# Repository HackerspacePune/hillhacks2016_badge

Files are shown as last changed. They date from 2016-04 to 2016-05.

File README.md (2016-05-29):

PCB badge for hillhacks.in
==========================

Designed in kicad 4.0.2

Based on Adafruit trinket and Digispark designs. Can use either Adafruit's 
trinket/gemma bootloader, or micronucleus(which digispark uses).
Reverse protection for USB and battery with schottky diodes(and supply 
selection also), no voltage regulator, Zener diodes are to clip D+/D- 
voltage level to within USB spec. 1.5k on D- is part of USB spec's Low 
speed USB detection.

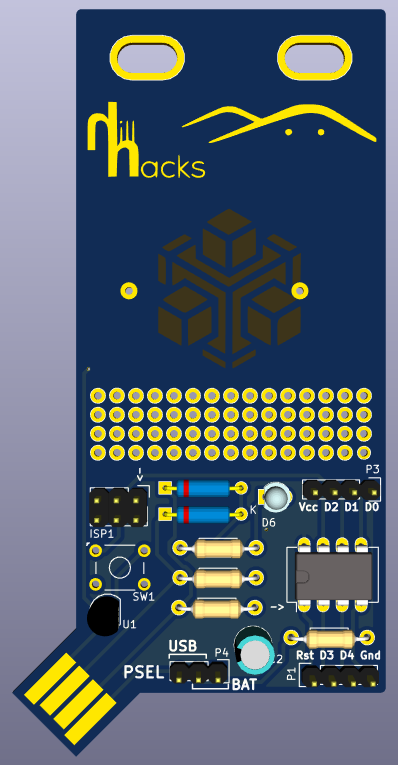
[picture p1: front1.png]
Hillhacks badge


Hillhacks logo is from header on site.

Design uses a footprint(pcb_USB-A) from Inversepath's Usbarmory kicad design https://github.com/inversepath/usbarmory/

Firmware
========

Bootloader: Please follow [these instructions](https://learn.adafruit.com/introducing-trinket/repairing-bootloader) for
installing Adafruit Trinket bootloader onto your badge. This allows you to upload 'sletches' to the badge without an external programmer.

Arduino IDE: Set up arduino IDE to work with your badge from [here](https://learn.adafruit.com/introducing-trinket/setting-up-with-arduino-ide).

Hardware
========

Please see [Schematic.pdf](Schematic.pdf) for schematic. Pin PB0(D0 for arduino) is
connected to push button. PB1(D1) is connected to LED.

NOTE: The button footprint is rotated by 90 degrees by mistake, so you need to bend the button
leads so they can be fit the PCB roated. 

NOTE2: the battery holder pins need to be bent out a bit
to fit the PCB.

Example code
============

Please see [/examples/HillhacksBadge.ino](/examples/HillhacksBadge.ino) for Mitch's example sketch.

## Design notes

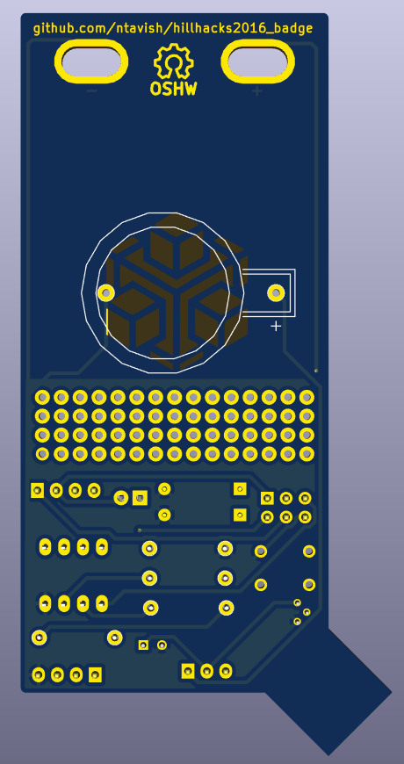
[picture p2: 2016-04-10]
back1.png

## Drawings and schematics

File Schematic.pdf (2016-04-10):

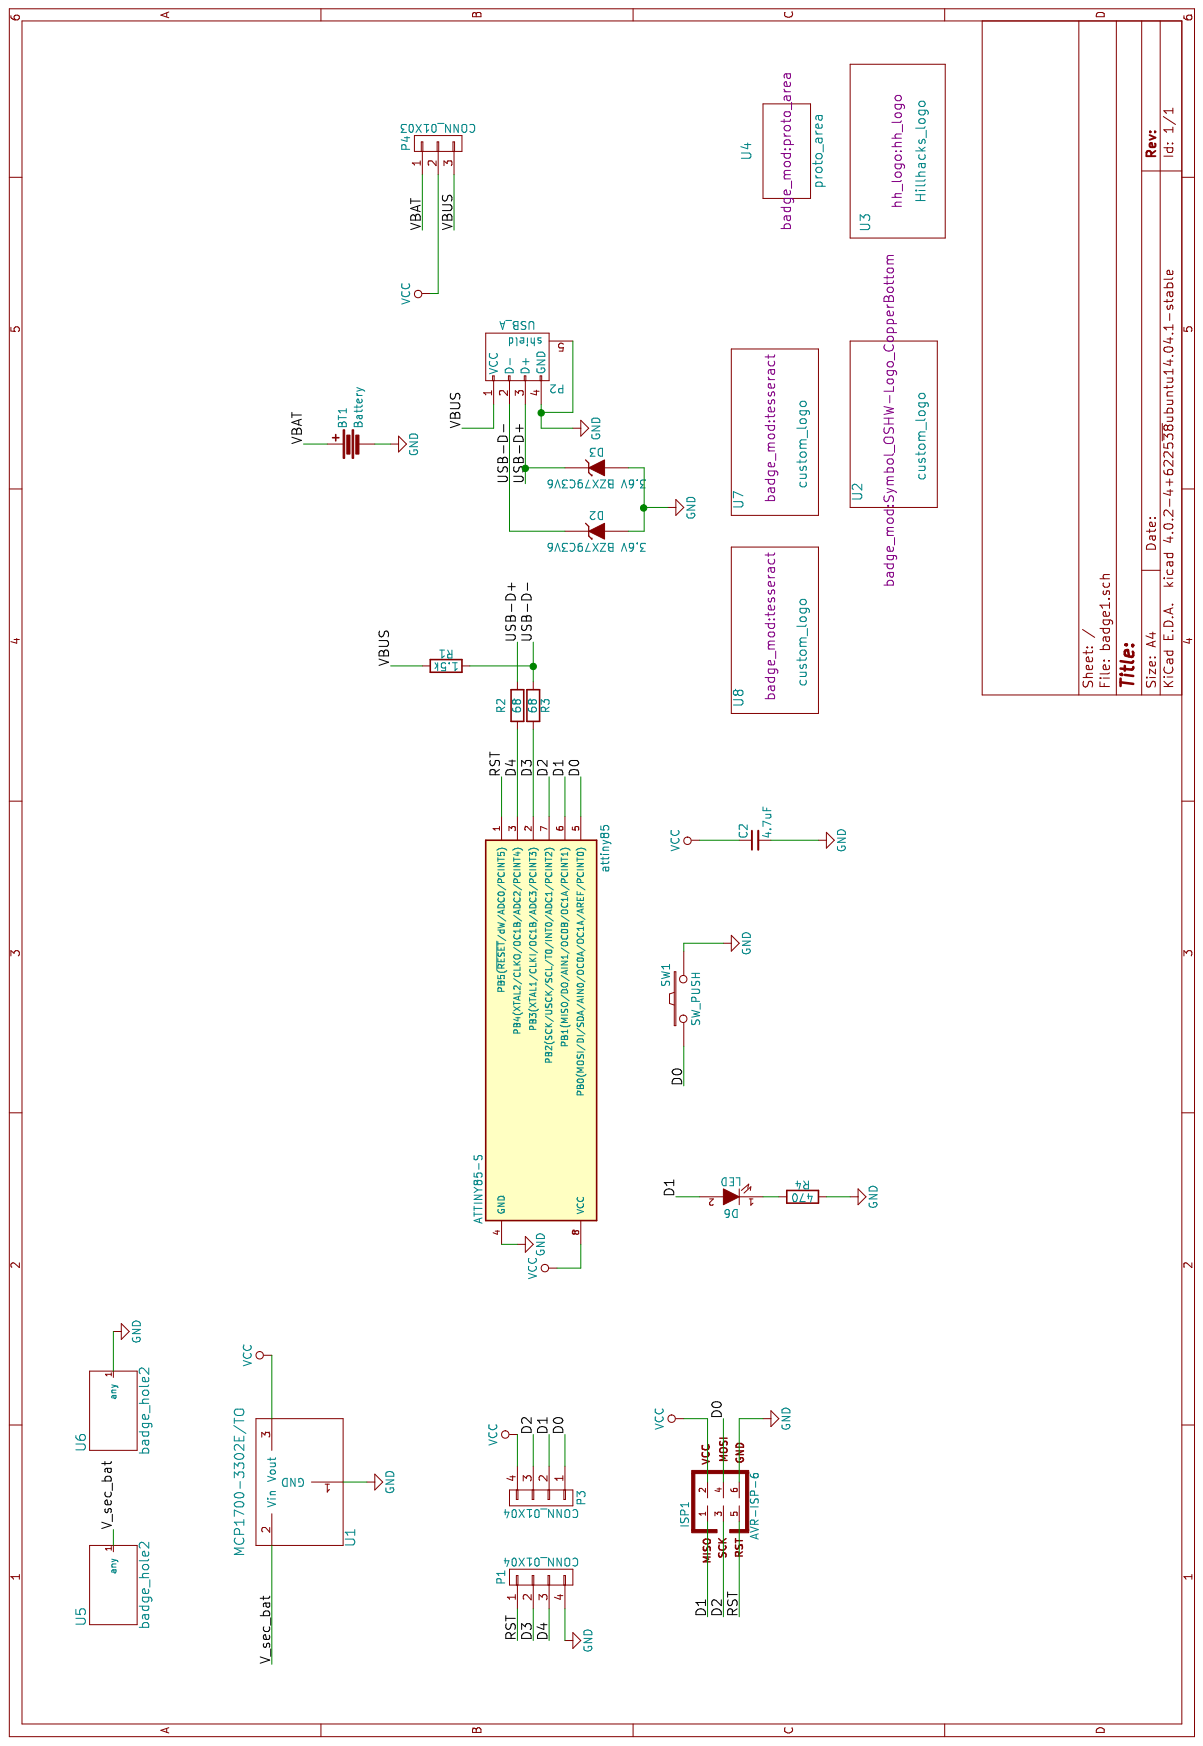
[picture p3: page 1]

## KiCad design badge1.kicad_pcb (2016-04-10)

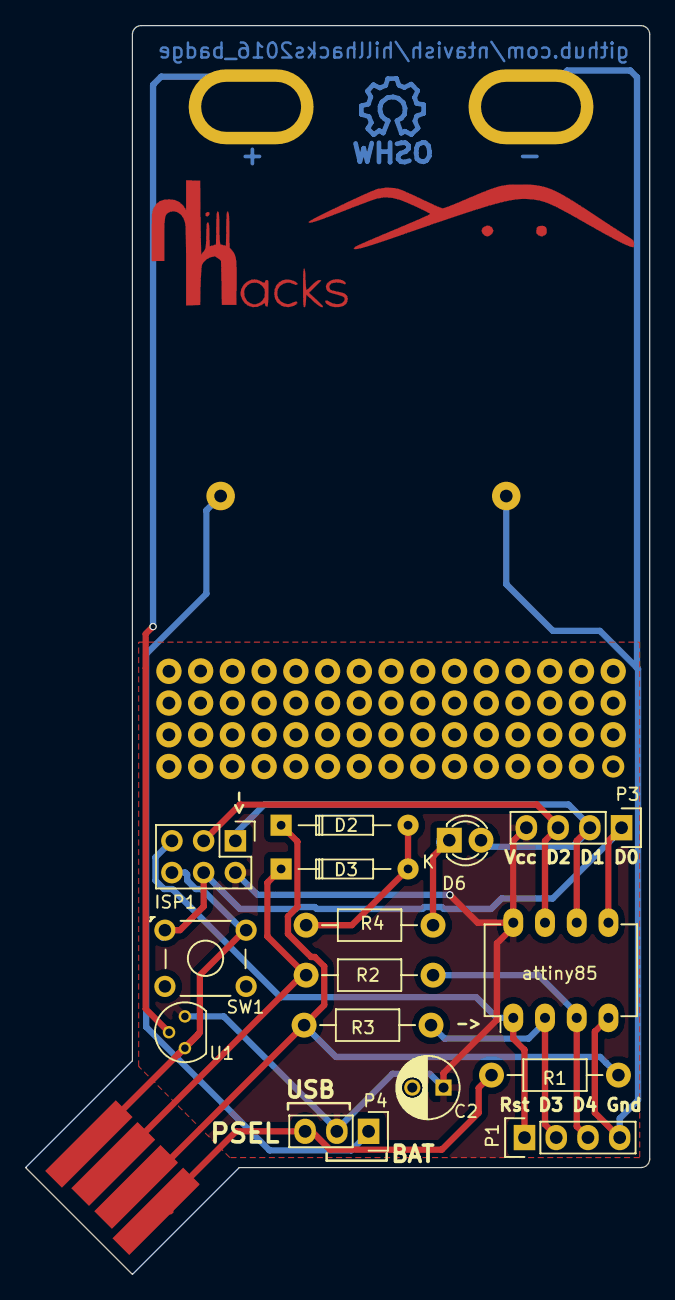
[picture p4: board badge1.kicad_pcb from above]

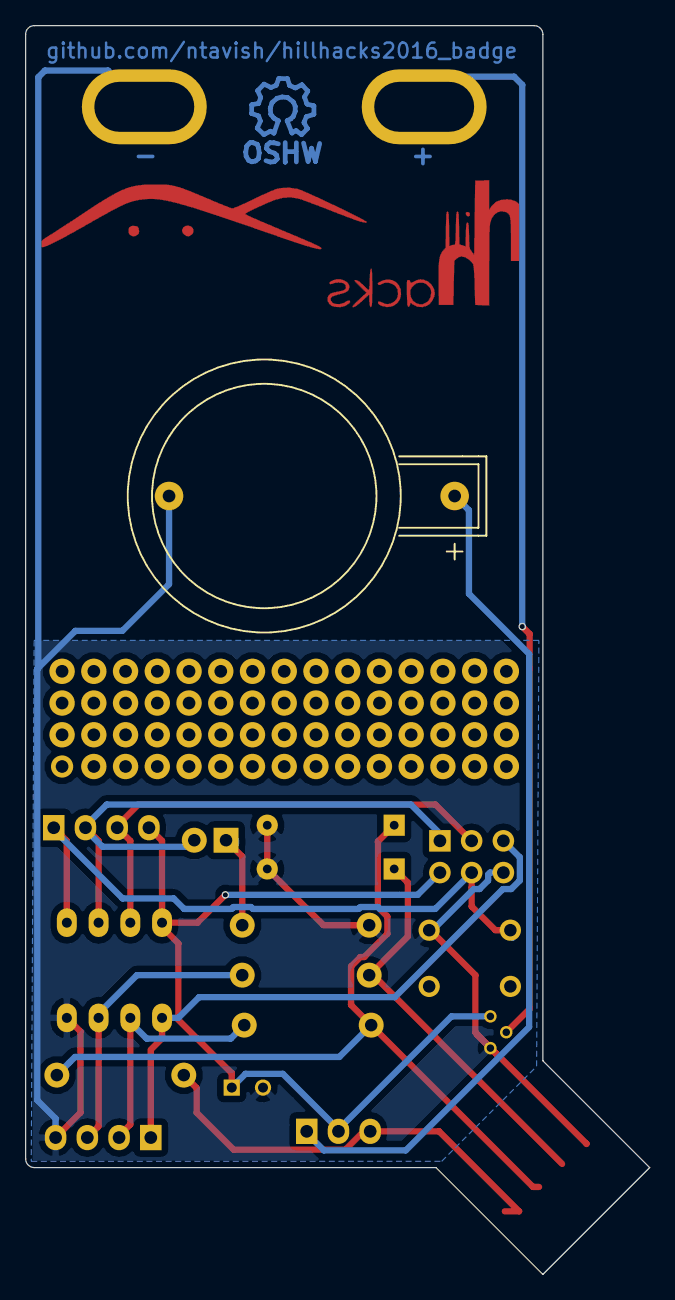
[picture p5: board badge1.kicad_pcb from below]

Board: 2 copper layers, 50.0 x 100.0 mm, 24 parts (2 on the bottom side), 14 nets.

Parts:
BT1: Battery; CR2032H
C2: 4.7uF; C_Radial_D5_L11_P2.5
D2, D3: 3.6V BZX79C3V6; Diode_DO-35_SOD27_Horizontal_RM10
D6: LED; LED-3MM
ISP1: AVR-ISP-6; Pin_Header_Straight_2x03
P1, P3: CONN_01X04; Pin_Header_Straight_1x04
P2: USB_A; usb-PCB
P4: CONN_01X03; Pin_Header_Straight_1x03
R1: 1.5k; Resistor_Horizontal_RM10mm
R2, R3: 68; Resistor_Horizontal_RM10mm
R4: 470; Resistor_Horizontal_RM10mm
SW1: SW_PUSH; OPL_DIP_BUTTON_TS-1109_BEST_SHENZEN
U1: MCP1700-3302E/TO; TO-92_Molded_Narrow
U2: custom_logo; Symbol_OSHW-Logo_CopperBottom
U3: Hillhacks_logo; hh_logo
U4: proto_area
U5, U6: badge_hole2; badge_hole_6mmx3mm(+2mmCu)
U7, U8: custom_logo; tesseract
attiny85: ATTINY85-S; DIP-8_W7.62mm_LongPads

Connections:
/D0: ISP1.4, P3.1, SW1.1, attiny85.5
/D1: D6.2, ISP1.1, P3.2, attiny85.6
/D2: ISP1.3, P3.3, attiny85.7
/D3: P1.2, R3.2, attiny85.2
/D4: P1.3, R2.2, attiny85.3
/RST: ISP1.5, P1.1, attiny85.1
/USB-D+: D3.1, P2.3, R2.1
/USB-D-: D2.1, P2.2, R1.1, R3.1
/VBAT: BT1.1, P4.1
/VBUS: P2.1, P4.3, R1.2
/V_sec_bat: U1.2, U5.1
GND: BT1.2, C2.2, D2.2, D3.2, ISP1.6, P1.4, P2.4, R4.2, SW1.2, U1.1, U6.1, attiny85.4
unnamed: D6.1, R4.1
VCC: C2.1, ISP1.2, P3.4, P4.2, U1.3, attiny85.8

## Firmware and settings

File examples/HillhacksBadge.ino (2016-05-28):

/*
  Hillhacks Badge example sketch

 When first powered up, LED on D1 blinks on and off at 100ms intervals.
 After push button on D0:  LED fades in and out.
 After push button again:  LED blinks kind of randomly
 After push button again:  LED fades in and out quickly
 Push button again: back to beginning to blink LED on and off at 100ms intervals.
 etc.

 The circuit:
 * LED attached from pin 1 to ground
 * pushbutton attached to pin 0 to ground


Hacked from Arduino example sketches:  Blink and Fade
 This example code is in the public domain.
*/

// constants won't change values
const int buttonPin = 0;         // the number of the pushbutton pin
const int ledPin =  1;           // the number of the LED pin
const int MAX_BUTTON_COUNT = 4;  // max number of cool things that can happen by pushing the button
const int MAX_RAND_BLINK = 10;   // number of different blink rates for the random blink for the 3rd button press

// variables will change values
int buttonCount = 0;         // keep track of the number of times the button is pushed

int brightness = 0;          // how bright the LED is when we're in case 1)
int fadeAmount = 5;          // how many points to fade the LED by when we're in case 1)

int randomBlinkState = 0;    // keeps track of where we're at in the random blinking for case 2


// see if the button is being pushed, and if so, increment the buttonCount
int readButton() {  
  int buttonState = 0;   // variable for reading the pushbutton status

  // read the state of the pushbutton value:
  buttonState = digitalRead(buttonPin);  // buttonState will be LOW if button is being pushed

  // if button is being pushed, increment the buttonCount
  if (buttonState == LOW) {
    buttonCount++;
    // reset the buttonCount to 0 if we've reached the max number
    if (buttonCount == MAX_BUTTON_COUNT) {
      buttonCount = 0;
    }
  }  

  // wait for button to stop being pressed
  while (buttonState == LOW) {
    buttonState = digitalRead(buttonPin);  // buttonState will be LOW if button is still being pushed
    delay(10);
  }
}


void setup() {
  // initialize the LED pin as an output:
  pinMode(ledPin, OUTPUT);
  // initialize the pushbutton pin as an input:
  pinMode(buttonPin, INPUT);
  digitalWrite(buttonPin, HIGH);
}

void loop() {
  // See if the button is being pushed -- buttonCount is automatically incremented if it is
  readButton();

  // The LED will do something different depending on the number of times the button has been pushed
  switch(buttonCount) {

    // For case 0, the LED blinks on and off at 10msec intervals
    case 0 :
      digitalWrite(ledPin, HIGH); 
      delay(100);
      digitalWrite(ledPin, LOW);
      delay(100);

      break;  // end of case 0


    // For case 1, the LED fades in and out
    case 1 :
      // set the brightness of the LED on pin 1:
      analogWrite(ledPin, brightness);

      // change the brightness for next time through the loop:
      brightness = brightness + fadeAmount;

      // reverse the direction of the fading at the ends of the fade:
      if (brightness == 0 || brightness == 255) {
        fadeAmount = -fadeAmount ;
      }

      // wait for 30 milliseconds to see the dimming effect
      delay(30);

      break;  // end of case 1


    // For case 2, the LED blinks on and off kind of randomly
    case 2 :

      switch (randomBlinkState) {
        case 0:
          digitalWrite(ledPin, HIGH); 
          delay(100);
          digitalWrite(ledPin, LOW);
          delay(100);
          // increment to next random blink state, and reset to 0 if reached the max state
          randomBlinkState++;
          if (randomBlinkState == MAX_RAND_BLINK) randomBlinkState = 0;
          break;
        case 1:
          digitalWrite(ledPin, HIGH); 
          delay(100);
          digitalWrite(ledPin, LOW);
          delay(500);
          // increment to next random blink state, and reset to 0 if reached the max state
          randomBlinkState++;
          if (randomBlinkState == MAX_RAND_BLINK) randomBlinkState = 0;
          break;
        case 2:
          digitalWrite(ledPin, HIGH); 
          delay(100);
          digitalWrite(ledPin, LOW);
          delay(100);
          // increment to next random blink state, and reset to 0 if reached the max state
          randomBlinkState++;
          if (randomBlinkState == MAX_RAND_BLINK) randomBlinkState = 0;
          break;
        case 3:
          digitalWrite(ledPin, HIGH); 
          delay(500);
          digitalWrite(ledPin, LOW);
          delay(500);
          // increment to next random blink state, and reset to 0 if reached the max state
          randomBlinkState++;
          if (randomBlinkState == MAX_RAND_BLINK) randomBlinkState = 0;
          break;
        case 4:
          digitalWrite(ledPin, HIGH); 
          delay(50);
          digitalWrite(ledPin, LOW);
          delay(100);
          // increment to next random blink state, and reset to 0 if reached the max state
          randomBlinkState++;
          if (randomBlinkState == MAX_RAND_BLINK) randomBlinkState = 0;
          break;
        case 5:
          digitalWrite(ledPin, HIGH); 
          delay(50);
          digitalWrite(ledPin, LOW);
          delay(100);
          // increment to next random blink state, and reset to 0 if reached the max state
          randomBlinkState++;
          if (randomBlinkState == MAX_RAND_BLINK) randomBlinkState = 0;
          break;
        case 6:
          digitalWrite(ledPin, HIGH); 
          delay(50);
          digitalWrite(ledPin, LOW);
          delay(100);
          // increment to next random blink state, and reset to 0 if reached the max state
          randomBlinkState++;
          if (randomBlinkState == MAX_RAND_BLINK) randomBlinkState = 0;
          break;
        case 7:
          digitalWrite(ledPin, HIGH); 
          delay(100);
          digitalWrite(ledPin, LOW);
          delay(500);
          // increment to next random blink state, and reset to 0 if reached the max state
          randomBlinkState++;
          if (randomBlinkState == MAX_RAND_BLINK) randomBlinkState = 0;
          break;
        case 8:
          digitalWrite(ledPin, HIGH); 
          delay(500);
          digitalWrite(ledPin, LOW);
          delay(100);
          // increment to next random blink state, and reset to 0 if reached the max state
          randomBlinkState++;
          if (randomBlinkState == MAX_RAND_BLINK) randomBlinkState = 0;
          break;
        case 9:
          digitalWrite(ledPin, HIGH); 
          delay(100);
          digitalWrite(ledPin, LOW);
          delay(100);
          // increment to next random blink state, and reset to 0 if reached the max state
          randomBlinkState++;
          if (randomBlinkState == MAX_RAND_BLINK) randomBlinkState = 0;
          break;
      }
      
      break;  // end of case 2


    // For case 1, the LED fades in and out
    case 3 :
      // set the brightness of the LED on pin 1:
      analogWrite(ledPin, brightness);

      // change the brightness for next time through the loop:
      brightness = brightness + fadeAmount;

      // reverse the direction of the fading at the ends of the fade:
      if (brightness == 0 || brightness == 255) {
        fadeAmount = -fadeAmount ;
      }

      // wait for 5 milliseconds to see the dimming effect
      delay(5);

      break;  // end of case 3

  }
}

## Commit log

2016-03-02 initial release
    [badge1.kicad_pcb, badge1.sch]
2016-03-03 Updated with @anool's comments.
    [badge1.kicad_pcb, badge1.sch]
2016-03-09 added tessearact logo. smoothed 3 corners.
    [badge1.kicad_pcb, badge1.sch]
2016-03-09 hide U4
    [badge1.kicad_pcb]
2016-03-09 fixed positions of silkscreen texts, tesseract logo to F.Mask
    [badge1.kicad_pcb]
2016-03-12 minor changes. increase via size. update rendering with colour.
    [badge1.kicad_pcb, badge1.sch]
2016-03-12 added OPL button footprint
2016-04-07 fixed mistakes and made button the reset button. added more legend.
    [badge1.kicad_pcb, badge1.sch]
2016-04-10 Update schematic/layout with fixes. Update readme for small howto.
    [badge1.kicad_pcb, badge1.sch]
